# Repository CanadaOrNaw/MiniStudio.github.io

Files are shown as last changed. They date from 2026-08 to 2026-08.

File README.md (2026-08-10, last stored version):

# Mini Studio 16 website

This repository publishes the static Mini Studio 16 project site.

The firmware, CAD sources, tests, documentation, and development history live in [CanadaOrNaw/Mini-Studio-16](https://github.com/CanadaOrNaw/Mini-Studio-16). The files here are a dependency-free build artifact generated from that repository.

## GitHub Pages setting

In **Settings → Pages**, choose **Deploy from a branch**, select **main** and **/(root)**, then save.

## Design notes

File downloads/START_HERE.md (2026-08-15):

# Start here: Mini Studio 16

This page is for someone who has never flashed an ESP32 before. You do not
need to install a DAW or compile source code.

Mini Studio 16 is still a pre-hardware alpha. The downloadable firmware passes
desktop tests and compiles for the Cardputer-ADV, but the first physical-device
test has not happened yet. Keep the original M5Stack factory firmware available
so you can restore it if needed.

## You need

- one **M5Stack Cardputer-ADV** (not the older Cardputer);
- one USB-C **data** cable—some charging-only cables do not carry data;
- one FAT32 microSD card, 32 GB or smaller for the least-friction first test;
- a Windows, macOS or Linux computer;
- the optional printed cradle only if you want it.

The Audio Cap is optional. Do not buy or assemble it for the first Cardputer
test. Its exact shopping list and two-part enclosure are covered later in
[`AUDIO_CAP_BUILD_GUIDE.md`](AUDIO_CAP_BUILD_GUIDE.md).

## The three steps

### 1. Download the verified package

The easy way — no account needed:

1. Open the [Releases page](https://github.com/CanadaOrNaw/Mini-Studio-16/releases/latest).
2. Under **Assets**, download the one file whose name ends in
   `-package.zip`. Ignore the automatic "Source code" downloads — those are
   the program's source, not the ready-to-flash package.
3. Unzip it into a new empty folder.

The developer way — only if you want the newest unreleased build:

1. Open [Build v3 alpha](https://github.com/CanadaOrNaw/Mini-Studio-16/actions/workflows/build-v3-alpha.yml).
2. Open the newest green run for the `main` branch.
3. At the bottom, download the artifact named
   `microgroove-v3-alpha-cardputer-adv`. **This path always requires a free
   GitHub account sign-in, and each run's artifact is deleted about 90 days
   after the run** — if the download link is gone or gives a 404, use the
   Releases page above instead.
4. Unzip it into a new empty folder.

The file for a first Cardputer flash is:

`mini-studio-16-dual-role.bin`

It contains both USB modes and boots into Normal mode first. Do not flash the
smaller application-only `firmware.bin` at address zero.

### 2. Flash it

Follow [`FLASHING.md`](FLASHING.md). That guide includes Windows, macOS and
Linux commands, how to find the port, the Cardputer G0 download-mode sequence,
the exact `0x0` address, recovery steps and separate optional Audio Cap flashing.

### 3. Prepare the SD card

1. Format the card as **FAT32** with an MBR partition table ("MBR" is the
   older, more compatible partition style — most cards 32 GB or smaller ship
   that way already). Windows: right-click the card in Explorer → Format →
   FAT32 (Windows cannot FAT32-format cards larger than 32 GB — use a 32 GB
   or smaller card). macOS: Disk Utility → Erase → format "MS-DOS (FAT)",
   scheme "Master Boot Record". Linux: `mkfs.vfat -F 32` on the card's
   partition.
2. Open `Mini-Studio-16_SD.zip` from the downloaded package.
3. Copy its `groovebox` folder to the root of the SD card.
4. Safely eject the card and insert it into the powered-off Cardputer.
5. Switch the Cardputer on.

The first screen lets you keep Normal USB mode or switch to USB Host mode. Use
Normal mode for the first test. Press any key other than `Tab` to continue.

## Make the first sound

1. Keep headphone volume low or use the built-in speaker.
2. Hold the `=` key (LOAD) until the load completes — a hold takes about half
   a second.
3. Tap the `n` key (SONG) so the whole factory song plays, not just one
   pattern.
4. Press the space bar (PLAY).
4. Use the [interactive button map](https://canadaornaw.github.io/MiniStudio.github.io/#controls)
   or the included `mini-studio-16-button-layout.svg` while learning the pages.

The factory project uses built-in drum engines, so it should make sound even if
sample files were copied incorrectly.

After that basic regression, tap `ctrl` to CHORD and press
`fn shift a s d f g` to play I–VII. Continue to KO for momentary punch
effects and MEDO for the five performance roles. The complete context map and
manual are included in the package.

## If it does not work

- Nothing appears as a serial port: try another known data cable and USB port.
- Flashing cannot connect: repeat the exact G0 sequence in `FLASHING.md`.
- It boots but the SD card is missing: reformat as FAT32/MBR and copy the
  `groovebox` folder—not the outer ZIP—to the card root.
- It makes no sound: lower then raise the Mini Studio volume, unplug headphones,
  and rerun the factory-project steps.
- It resets, becomes hot, smells unusual or the display flickers: power it off
  and record the symptom before trying again.

Once the basic boot/audio pass works, use
[`CARDPUTER_TESTING.md`](https://github.com/CanadaOrNaw/Mini-Studio-16/blob/main/docs/CARDPUTER_TESTING.md) and record measured results. That
physical evidence is the remaining engineering gate.

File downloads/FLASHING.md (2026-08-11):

# Flash Mini Studio 16 without compiling it

This guide writes one already-built image to a Cardputer-ADV. It does not
require PlatformIO, Arduino IDE or a DAW.

## Before you start

You need the unzipped download described in [`START_HERE.md`](START_HERE.md)
(the Releases package, or the sign-in-gated Actions artifact for unreleased
builds), a USB-C **data** cable and Python 3.

Install the pinned flashing tool:

| Computer | Command |
| --- | --- |
| Windows PowerShell | `py -m pip install esptool==4.8.1` |
| macOS Terminal | `python3 -m pip install esptool==4.8.1` |
| Linux terminal | `python3 -m pip install --user esptool==4.8.1` |

In the commands below, Windows users type `py` where the guide says `python3`.

## 1. Find the Cardputer port

1. Set the Cardputer side power switch to **OFF**.
2. Hold the side `G0` button.
3. While holding `G0`, connect the USB-C data cable to the computer.
4. Release `G0`. The screen may stay blank; that is normal download mode.

M5Stack documents this same sequence in its
[Cardputer-ADV download-mode guide](https://docs.m5stack.com/en/core/Cardputer-Adv).

Find the new port:

- Windows: open **Device Manager → Ports (COM & LPT)** and note a name such as
  `COM5`.
- macOS: run `ls /dev/cu.usb*` and note the new path.
- Linux: run `ls /dev/ttyACM* /dev/ttyUSB* 2>/dev/null` and note the new path.

Use that exact value in place of `PORT` below.

## 2. Flash the combined Cardputer image

Open a terminal in the unzipped artifact folder. First erase the old flash:

```bash
python3 -m esptool --chip esp32s3 --port PORT erase_flash
```

Then write the combined image at address `0x0`:

```bash
python3 -m esptool --chip esp32s3 --port PORT --baud 460800 write_flash 0x0 mini-studio-16-dual-role.bin
```

Wait for `Hash of data verified`. Disconnect USB, move the side switch to ON,
then reconnect USB only if you want charging/serial. The first boot selects
Normal USB mode. `Tab` switches between Normal and USB Host after a validated
reboot; it does not require another flash.

Erasing replaces the factory firmware and settings stored in flash. It does not
erase the removable microSD card.

## 3. Verify the downloaded files (recommended)

The artifact includes `SHA256SUMS.txt`. On macOS or Linux:

```bash
sha256sum -c SHA256SUMS.txt
```

macOS may provide `shasum -a 256` instead of `sha256sum`; compare the result for
`mini-studio-16-dual-role.bin` with its line in `SHA256SUMS.txt`. On Windows:

```powershell
certutil -hashfile mini-studio-16-dual-role.bin SHA256
```

Compare the printed value with the same filename in `SHA256SUMS.txt`. Do not
flash a file whose hash differs.

## Optional: flash the ATOM Lite Audio Cap controller

Do this **before** assembling the cap. The ATOM must be by itself—not connected
to the Cardputer, PCM1808 or power harness.

1. Connect the ATOM Lite to the computer with its USB-C data cable. M5Stack says
   the original ATOM Lite enters download mode when connected for flashing.
2. Find its port using the same operating-system steps above.
3. In the artifact folder run:

```bash
python3 -m esptool --chip esp32 --port PORT erase_flash
python3 -m esptool --chip esp32 --port PORT --baud 460800 write_flash 0x0 mini-studio-audio-cap-atom-lite/mini-studio-audio-cap-atom-lite.bin
```

4. Wait for hash verification and unplug the programming cable.
5. Continue with [`AUDIO_CAP_BUILD_GUIDE.md`](AUDIO_CAP_BUILD_GUIDE.md).

The ATOM's USB cable is only used while programming. It is not present in the
finished one-plug Cardputer-powered cap.

## Recovery and common errors

| Message or symptom | What to do |
| --- | --- |
| `Failed to connect` | Repeat OFF → hold G0 → connect USB → release G0; then retry. |
| Port disappears | Try a different data cable/USB port and avoid an unpowered hub. |
| `Permission denied` on Linux | Add your user to the serial-port group (often `dialout`), sign out/in, then retry. Do not run random commands as root. |
| Write fails at high baud | Repeat the write command with `--baud 115200`. |
| Cardputer boot-loops after a completed write | Re-enter G0 mode, erase, verify the image hash, and write again at `0x0`. |
| Need the factory firmware | Follow M5Stack's [Cardputer-ADV restore guide](https://docs.m5stack.com/en/guide/restore_factory/cardputer_adv). |

Developers who intentionally want to compile or upload from source can use the
PlatformIO commands in the main README. Beginners should use the merged images
above because they contain the bootloader, partition table and application at
the correct addresses.

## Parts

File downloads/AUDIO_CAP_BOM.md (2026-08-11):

# Audio Cap exact shopping list

This page is generated from `hardware/audio-cap/bom.json`. Every link
opens one exact product SKU—not a search or category page. Price and stock
can change. If a link is unavailable, search the printed manufacturer part
number or ASIN and do not substitute a visually similar part.

Marketplace listings (Amazon ASINs) rot without notice and cannot be
checked by automation; they were last hand-verified on 2026-08-11.
Before paying, confirm the page still shows the exact part named in
its row — for the PCM1808 module that means the master-mode variant
with its own onboard oscillator (a small metal can on the board),
an installed I2S header, and a 3.5 mm jack.

Buy one row of each item unless the quantity column says otherwise. An adult
should place orders and supervise cutting/stripping the four power leads.

## Canada

| Qty | Exact part | Seller SKU | Buy |
| ---: | --- | --- | --- |
| 1 | **M5Stack C008** — ATOM Lite ESP32 controller with factory-installed USB-C and Grove connectors | `2221-C008-ND` | [DigiKey Canada](https://www.digikey.ca/en/products/detail/m5stack-technology-co-ltd/C008/12088545) |
| 1 | **Rakstore ASIN B09CDCLXQC** — Preassembled PCM1808 stereo line-input I2S module with 3.5 mm jack, installed I2S header and USB-C 5 V input | `ASIN B09CDCLXQC` | [Amazon Canada](https://www.amazon.ca/Rakstore-PCM1808-Stereo-Single-Ended-Digital/dp/B09CDCLXQC) |
| 1 | **Samtec TSW-107-08-G-D** — 2x7, 2.54 mm through-hole male terminal strip; 5.84 mm mating posts and 5.08 mm wire-side tails | `612-TSW-107-08-G-D-ND` | [DigiKey Canada](https://www.digikey.ca/en/products/detail/samtec-inc/TSW-107-08-G-D/1101667) |
| 1 | **Adafruit 4635** — Pack of 40 factory-crimped 200 mm male-to-female silicone jumper leads, 24 AWG | `1528-4635-ND` | [DigiKey Canada](https://www.digikey.ca/en/products/detail/adafruit-industries-llc/4635/13157993) |
| 1 | **M5Stack A096** — Grove-to-Dupont conversion cable set, 20 cm, five male and five female sets | `2221-A096-ND` | [DigiKey Canada](https://www.digikey.ca/en/products/detail/m5stack-technology-co-ltd/A096/16679751) |
| 2 | **WAGO 221-413** — Three-port compact lever splice; one for +5 V and one for GND, hidden inside the cap | `2946-221-413-ND` | [DigiKey Canada](https://www.digikey.ca/en/products/detail/wago-corporation/221-413/13549610) |
| 1 | **MECCANIXITY ASIN B0DWK3NXG6** — Short USB-C male to red/black bare-wire 5 V pigtail, 22 AWG; hidden inside the cap | `ASIN B0DWK3NXG6` | [Amazon Canada](https://www.amazon.ca/MECCANIXITY-Pigtail-Connector-Equipment-Installed/dp/B0DWK3NXG6) |
| 2 | **Essentra Components 50M020040P006** — M2 x 0.4 x 6 mm nylon pan-head Phillips machine screw | `145-50M020040P006-ND` | [DigiKey Canada](https://www.digikey.ca/en/products/detail/essentra-components/50M020040P006/11639321) |
| 2 | **Essentra Components 04M020040HN** — M2 x 0.4 nylon hex nut | `RPC7084-ND` | [DigiKey Canada](https://www.digikey.ca/en/products/detail/essentra-components/04M020040HN/9677098) |

## United States

| Qty | Exact part | Seller SKU | Buy |
| ---: | --- | --- | --- |
| 1 | **M5Stack C008** — ATOM Lite ESP32 controller with factory-installed USB-C and Grove connectors | `2221-C008-ND` | [DigiKey](https://www.digikey.com/en/products/detail/m5stack-technology-co-ltd/C008/12088545) |
| 1 | **Rakstore ASIN B09CDCLXQC** — Preassembled PCM1808 stereo line-input I2S module with 3.5 mm jack, installed I2S header and USB-C 5 V input | `ASIN B09CDCLXQC` | [Amazon US](https://www.amazon.com/Rakstore-PCM1808-Stereo-Single-Ended-Digital/dp/B09CDCLXQC) |
| 1 | **Samtec TSW-107-08-G-D** — 2x7, 2.54 mm through-hole male terminal strip; 5.84 mm mating posts and 5.08 mm wire-side tails | `612-TSW-107-08-G-D-ND` | [DigiKey](https://www.digikey.com/en/products/detail/samtec-inc/TSW-107-08-G-D/1101667) |
| 1 | **Adafruit 4635** — Pack of 40 factory-crimped 200 mm male-to-female silicone jumper leads, 24 AWG | `1528-4635-ND` | [DigiKey](https://www.digikey.com/en/products/detail/adafruit-industries-llc/4635/13157993) |
| 1 | **M5Stack A096** — Grove-to-Dupont conversion cable set, 20 cm, five male and five female sets | `2221-A096-ND` | [DigiKey](https://www.digikey.com/en/products/detail/m5stack-technology-co-ltd/A096/16679751) |
| 2 | **WAGO 221-413** — Three-port compact lever splice; one for +5 V and one for GND, hidden inside the cap | `2946-221-413-ND` | [DigiKey](https://www.digikey.com/en/products/detail/wago-corporation/221-413/13549610) |
| 1 | **EAHOSUCC ASIN B0DCGJY4MR** — Short USB-C male to red/black bare-wire 5 V pigtail, 22 AWG; hidden inside the cap | `ASIN B0DCGJY4MR` | [Amazon US](https://www.amazon.com/EAHOSUCC-22AWG-Pigtail-Equipment-Installed/dp/B0DCGJY4MR) |
| 2 | **Essentra Components 50M020040P006** — M2 x 0.4 x 6 mm nylon pan-head Phillips machine screw | `145-50M020040P006-ND` | [DigiKey](https://www.digikey.com/en/products/detail/essentra-components/50M020040P006/11639321) |
| 2 | **Essentra Components 04M020040HN** — M2 x 0.4 nylon hex nut | `RPC7084-ND` | [DigiKey](https://www.digikey.com/en/products/detail/essentra-components/04M020040HN/9677098) |

## European Union

| Qty | Exact part | Seller SKU | Buy |
| ---: | --- | --- | --- |
| 1 | **M5Stack C008** — ATOM Lite ESP32 controller with factory-installed USB-C and Grove connectors | `2221-C008-ND` | [DigiKey Germany](https://www.digikey.de/en/products/detail/m5stack-technology-co-ltd/C008/12088545) |
| 1 | **Rakstore ASIN B0D1NNR21W** — Preassembled PCM1808 stereo line-input I2S module with 3.5 mm jack, installed I2S header and USB-C 5 V input | `ASIN B0D1NNR21W` | [Amazon Germany](https://www.amazon.de/-/en/RAKSTORE-PCM1808-Stereo-Single-Ended-Digital/dp/B0D1NNR21W) |
| 1 | **Samtec TSW-107-08-G-D** — 2x7, 2.54 mm through-hole male terminal strip; 5.84 mm mating posts and 5.08 mm wire-side tails | `612-TSW-107-08-G-D-ND` | [DigiKey Germany](https://www.digikey.de/en/products/detail/samtec-inc/TSW-107-08-G-D/1101667) |
| 1 | **Adafruit 4635** — Pack of 40 factory-crimped 200 mm male-to-female silicone jumper leads, 24 AWG | `1528-4635-ND` | [DigiKey Germany](https://www.digikey.de/en/products/detail/adafruit-industries-llc/4635/13157993) |
| 1 | **M5Stack A096** — Grove-to-Dupont conversion cable set, 20 cm, five male and five female sets | `2221-A096-ND` | [DigiKey Germany](https://www.digikey.de/en/products/detail/m5stack-technology-co-ltd/A096/16679751) |
| 2 | **WAGO 221-413** — Three-port compact lever splice; one for +5 V and one for GND, hidden inside the cap | `2946-221-413-ND` | [DigiKey Germany](https://www.digikey.de/en/products/detail/wago-corporation/221-413/13549610) |
| 1 | **Greluma ASIN B0DNF37FPX** — Short USB-C male to red/black bare-wire 5 V pigtail, 22 AWG; hidden inside the cap | `ASIN B0DNF37FPX` | [Amazon Germany](https://www.amazon.de/-/en/Greluma-22AWG-Pigtail-Cable-Power/dp/B0DNF37FPX) |
| 2 | **Essentra Components 50M020040P006** — M2 x 0.4 x 6 mm nylon pan-head Phillips machine screw | `145-50M020040P006-ND` | [DigiKey Germany](https://www.digikey.de/en/products/detail/essentra-components/50M020040P006/11639321) |
| 2 | **Essentra Components 04M020040HN** — M2 x 0.4 nylon hex nut | `RPC7084-ND` | [DigiKey Germany](https://www.digikey.de/en/products/detail/essentra-components/04M020040HN/9677098) |

## Do not substitute these details

- The harness is Adafruit 4635, **24 AWG**. Ordinary 28-AWG jumper leads
  are not allowed in the WAGO power branches.
- The PCM1808 listing must show an installed I2S header, 3.5 mm input and
  USB-C 5 V input, and the board must be no larger than 50.5 × 30.5 mm.
- The cap header is Samtec `TSW-107-08-G-D`; print and use the fit gauge
  before printing the complete enclosure.
- The USB-C pigtail stays hidden inside the closed cap. It is not a second
  external power cable.

Continue with [`AUDIO_CAP_BUILD_GUIDE.md`](AUDIO_CAP_BUILD_GUIDE.md).

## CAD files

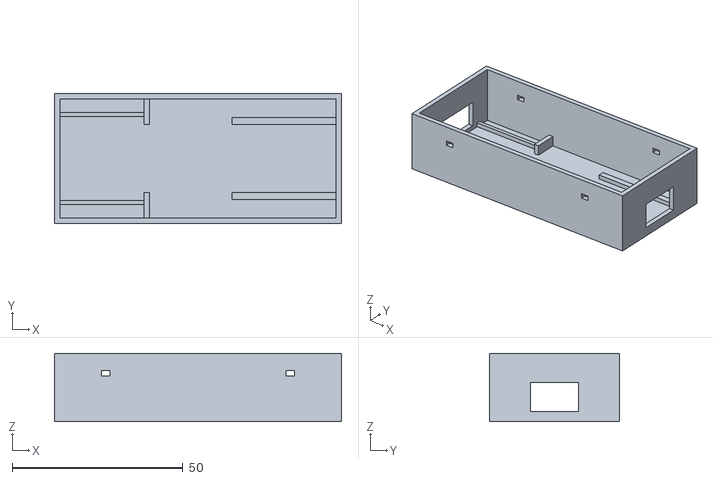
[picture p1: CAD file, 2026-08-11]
downloads/audio-cap-base.stl
84.0 x 38.0 x 20.0

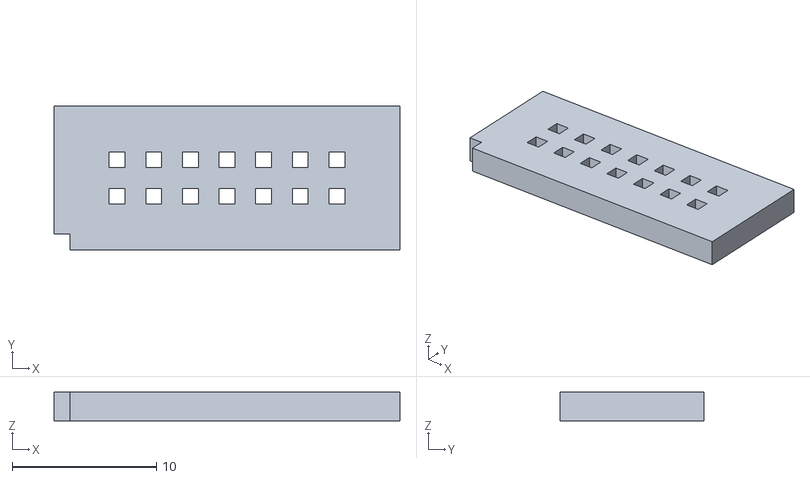
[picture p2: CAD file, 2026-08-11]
downloads/audio-cap-14pin-fit-gauge.stl
24.0 x 10.0 x 2.00

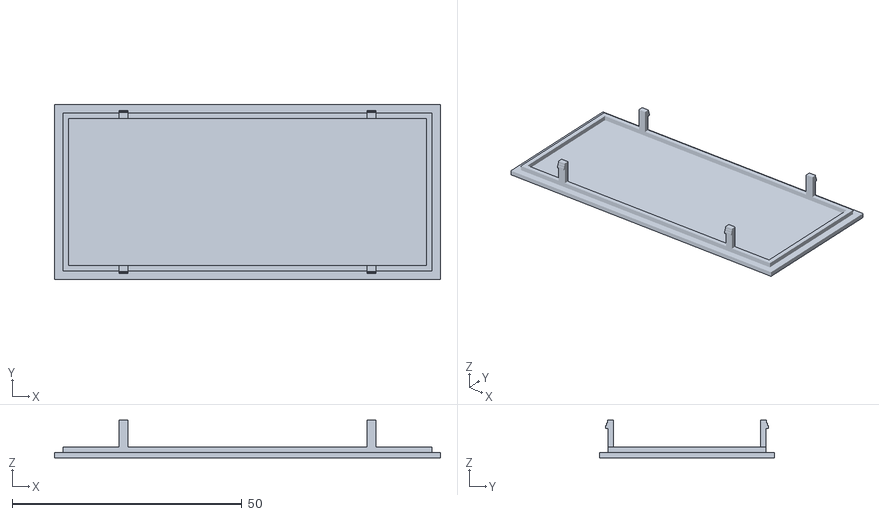
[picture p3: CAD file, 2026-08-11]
downloads/audio-cap-lid.stl
84.0 x 38.0 x 8.20

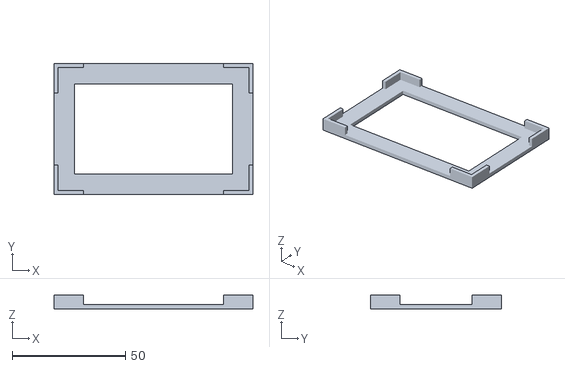
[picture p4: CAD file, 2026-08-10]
downloads/mini-studio-16-bench-cradle.stl
88.0 x 58.0 x 6.00

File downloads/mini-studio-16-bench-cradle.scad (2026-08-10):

// Mini Studio 16 open bench cradle for M5Stack Cardputer-ADV.
// Original parametric design; pre-hardware fit prototype.
// Published device envelope: 84 x 54 mm. Default clearance: 0.30 mm/side.

device_x = 84.0;
device_y = 54.0;
clearance = 0.30;
outer_x = 88.0;
outer_y = 58.0;
base_height = 2.0;
wall_height = 6.0;
center_opening_x = 70.0;
center_opening_y = 40.0;
side_clip_span_y = 32.0;
end_clip_span_x = 62.0;

cavity_x = device_x + 2 * clearance;
cavity_y = device_y + 2 * clearance;
wall_x = (outer_x - cavity_x) / 2;
wall_y = (outer_y - cavity_y) / 2;

module centered_cube(size) {
    translate([-size[0] / 2, -size[1] / 2, 0]) cube(size);
}

union() {
    // Ventilated bottom frame.
    difference() {
        centered_cube([outer_x, outer_y, base_height]);
        translate([0, 0, -0.1])
            centered_cube([center_opening_x, center_opening_y, base_height + 0.2]);
    }

    // Four open corner guides. Side/end centers stay clear for ports.
    for (sx = [-1, 1])
        for (sy = [-1, 1]) {
            translate([sx * (cavity_x / 2 + wall_x / 2),
                       sy * (cavity_y / 2 - side_clip_span_y / 4), 0])
                centered_cube([wall_x, side_clip_span_y / 2, wall_height]);
            translate([sx * (cavity_x / 2 - end_clip_span_x / 4),
                       sy * (cavity_y / 2 + wall_y / 2), 0])
                centered_cube([end_clip_span_x / 2, wall_y, wall_height]);
        }
}

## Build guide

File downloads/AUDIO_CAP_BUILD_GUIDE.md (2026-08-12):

# Build the Mini Studio 16 Audio Cap

This is the beginner version. An adult should supervise a child during printing,
wire stripping/crimping, first power and headphone use. Nothing is soldered and
no circuit board is ordered or fabricated.

## What you are making

When closed, the cap has a 3.5 mm line-input hole, one 14-pin plug, and four
small snap windows on its long sides. It plugs directly into the Cardputer.
There is no second power cord: the Cardputer powers it through the 14-pin
plug. The ATOM's physical button and status light are inside the closed lid
in this revision, so pairing and status use the Cardputer commands
(`cap-pair`, `cap-status`) shown in step 8; a button plunger and light window
are planned for enclosure rev-B.

## 1. Buy the parts

Open the human-readable
[`AUDIO_CAP_BOM.md`](AUDIO_CAP_BOM.md) and use the table for your region. It is
generated from the canonical [`hardware/audio-cap/bom.json`](https://github.com/CanadaOrNaw/Mini-Studio-16/blob/main/hardware/audio-cap/bom.json)
and tested to contain exact purchase SKUs for Canada, the United States and the
European Union.

| Qty | Part | The picture must show |
| ---: | --- | --- |
| 1 | M5Stack ATOM Lite C008 | white 24 mm square case, USB-C, Grove socket |
| 1 | Rakstore PCM1808 stereo I2S module (exact regional ASIN in BOM) | 3.5 mm jack; installed DOUT/BCK/LRCK/GND pins; USB-C 5 V input |
| 1 | Samtec `TSW-107-08-G-D` header | two rows of seven at 2.54 mm; exact 5.84/5.08 mm posts |
| 1 pack | Adafruit `4635` precrimped leads | 40 male-to-female leads; silicone insulation; **24 AWG** |
| 1 | M5Stack A096 Grove-to-Dupont lead set | factory-made Grove plug and separate Dupont ends |
| 2 | WAGO 221-413 three-port lever splices | genuine clear body/orange levers, three holes each |
| 1 | exact regional 22-AWG USB-C power pigtail from the BOM | male USB-C; red/black bare-wire ends |
| 2 | Essentra `50M020040P006` M2 x 6 nylon screws | module retainers; not lid fasteners |
| 2 | Essentra `04M020040HN` M2 nylon nuts | match the retainer screws |

Do not buy a bare PCM1808 chip, a board with empty header holes, or a module
larger than 50.5 x 30.5 mm. Do not substitute ordinary thin 28-AWG jumpers in
the power splices. Every BOM route names one exact SKU; if a link is out of
stock, search the printed manufacturer part number or ASIN rather than choosing
a look-alike.

## 2. Print the fit gauge first

Download and print:

1. `audio-cap-14pin-fit-gauge.stl`;
2. `audio-cap-base.stl` only after the header fits the gauge;
3. `audio-cap-lid.stl` after the purchased modules sit in the base.

Recommended first pass: PLA, 0.20 mm layers, 0.40 mm nozzle, 3 walls, 20% infill,
no support. The base and lid print flat exactly as downloaded — the lid prints
plate-down with its lip and four snap fingers pointing up, and is flipped over
for assembly. The gauge's one notched corner marks header pin 1 (the `G3`
end); keep that notch in the same corner as pin 1 whenever you test-fit.
Press the exact Samtec header into the small fit gauge by itself—never use the
Cardputer as a hammer. If it needs force, scale only X/Y by 101%, reprint the
gauge and record the result.

The generated models are watertight and have checked bounds. Their real fit is
unverified until the Cardputer and the exact retail module revision arrive.

## 3. Flash before assembly

The step-by-step first-time instructions are in [`FLASHING.md`](FLASHING.md).
Keep the cap parts away from the Cardputer. Connect only the ATOM Lite to your
computer with a normal USB-C data cable. The easiest route flashes the merged
`mini-studio-audio-cap-atom-lite.bin` from the verified Actions artifact at
offset `0x0`. Developers can instead run:

```bash
pio run -e mini-studio-audio-cap-atom-lite -t upload --upload-port PORT
```

Replace `PORT` with the port shown by PlatformIO. The RGB should light and the
serial monitor should print `MS16_AUDIO_CAP_READY`. Unplug the USB-C cable. It
is a programming cable used before assembly; it is not part of the finished cap.

## 4. Make the signal harness

Power must be off. Use the table exactly. Slide the female ends of five
Adafruit 4635 leads onto the rear pins of the 2x7 header, then slide the other
ends onto the named ATOM sockets. Double-check each lead against the table
before moving on — this revision has no keyed holder (planned for rev-B), so
the table and the gauge's pin-1 notch are your orientation references.

| Header position | Connect to |
| --- | --- |
| pin 1 G3 | ATOM G19 |
| pin 3 G4 | ATOM G21 |
| pin 5 G6 | ATOM G22 |
| pin 12 G13 | ATOM G23 |
| pin 13 G5 | ATOM G33 |

Leave header pins 2, 7, 8, 9, 10, 11 and 14 completely empty. Pin 2 is `5VIN`,
not cap power. A wrong power pin can damage the devices.

Connect the ADC using factory-crimped leads:

| PCM1808 | ATOM |
| --- | --- |
| DOUT | G25 |
| BCK | G26 (yellow Grove wire) |
| LRCK | G32 (white Grove wire) |
| GND | ground branch below |
| MCLK | leave empty |

## 5. Make the hidden power branch

This step uses **only the 24-AWG Adafruit 4635 leads and the 22-AWG USB-C
pigtail**. Common 28-AWG signal jumpers are not an allowed substitute. An adult
cuts the unused connector off four Adafruit leads—one for header 5 V, one for
header ground, one for ATOM 5 V and one for ATOM ground—and strips 9–11 mm at
the cut end.

Lift every orange lever. Put only straight bare copper under a lever, then close
it and tug gently. No copper should remain visible.

- `+5 V` splice: header pin 6 `5VOUT`, ATOM `5V`, red ADC-power wire.
- `GND` splice: header pin 4 `GND`, ATOM `GND`, black ADC-power wire.

Plug the short ADC-power connector into the PCM1808 module and tuck the entire
branch into its printed channel. Both lever splices and the ADC plug stay inside
the cap. No wire exits the enclosure.

The USB-C pigtail red/black ends are already bare; trim or restrip them to the
same 9–11 mm length if necessary. Never twist 5 V and GND together.

## 6. Check before power

Do these five checks aloud:

- “There is exactly one outside plug: the 14-pin header.”
- “Header pin 2 is empty.”
- “Header pin 6 goes to the +5 V splice.”
- “Header pin 4 goes to the ground splice.”
- “No loose copper can touch another pin.”

Use a multimeter continuity check before first power. `5VOUT` to GND must not
be a short. For the first prototype, place a multimeter in series with the
5VOUT branch and record idle, pairing and connected current. This temporary
bench measurement is removed before closing the finished cap.

## 7. Close and plug in

**Known rev-B gap — read before closing.** With straight precrimped jumpers in
the ATOM's bottom sockets, the ATOM-plus-housing stack is taller than this
revision's interior, so the current base closes over the PCM1808 and harness
but not over a fully jumpered ATOM. Until enclosure rev-B (deeper interior,
retainer bosses, wire channels), bench-test the cap open, or close the lid
with the ATOM resting beside its bay unlidded. Record the measured stack
height of your real parts in `CARDPUTER_TESTING.md` so rev-B uses evidence,
not estimates. The nylon M2 retainers from the BOM are for rev-B.

Seat the PCM1808 jack in its end window. Set the lid on the base — its
locating lip squares it automatically — then press down over each corner until
all four snap fingers click into the side windows. To reopen, press the two
visible nubs on one long side inward through their windows with a plastic
pick and lift; do not pry at the Cardputer.

With the Cardputer off, align the 14-pin plug (the bare header itself is not
keyed — match pin 1 `G3` to the gauge's notched corner and the EXT port's pin-1
end) and push straight in. Never offset it by one pin. Power the Cardputer from its battery or normal USB-C.

## 8. Use it

The line input accepts a stereo 3.5 mm source; start the source volume low.
Mini Studio sums it to mono. Line monitoring defaults off:

```bash
python tools/ministudio_cli.py --port PORT cap-status
python tools/ministudio_cli.py --port PORT cap-monitor 25
python tools/ministudio_cli.py --port PORT cap-pair
```

**First-power acceptance check (do this before anything else):** run
`cap-status` and look for `adc=1`. That single flag is the proof your
PCM1808 module is the required self-clocked master variant. If it stays
`adc=0`, or `cap-monitor` plays audio noticeably at the wrong pitch, the
purchased module is a slave-only or wrong-oscillator variant (PCM1808 needs
an external system clock the ATOM cannot supply — the module must carry its
own oscillator). Stop and exchange the module; no wiring change can fix it.
Record the result in `CARDPUTER_TESTING.md`.

Put one Bluetooth speaker/headset in pairing mode, then run `cap-pair` (the
ATOM's physical button also works whenever the lid is open). The first
discovered audio-rendering device is selected.

| RGB | Meaning |
| --- | --- |
| blue | ADC/bridge ready |
| purple | discovering/pair armed |
| green | Bluetooth audio connected |
| red | firmware/I2S/SPI fault |

## 9. First-hardware checklist

Do not call the cap finished until all results are recorded in
`docs/CARDPUTER_TESTING.md`: connector fit, 5VOUT current and sag, heat, silence
noise, line clipping level, left/right polarity, ten-minute CRC/sequence soak,
30-minute Bluetooth output, simultaneous SD recording, battery runtime, pair/
reconnect with three different sinks, and five power cycles.

If anything becomes hot, smells unusual, flickers when audio peaks, or reports
CRC/sequence errors, turn the Cardputer off and reopen the cap. Do not “fix” a
power problem by adding a second power cable; record the failure and revise the
module choice or power budget while preserving the one-plug design.

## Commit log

2026-08-10 Publish Mini Studio 16 website
    [mini-studio-16-bench-cradle.scad, mini-studio-16-bench-cradle.stl]
2026-08-10 Publish Audio Cap build package and beginner guides
    [mini-studio-audio-cap-base.stl, mini-studio-audio-cap-bom.csv, mini-studio-audio-cap-lid.stl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]
2026-08-10 Remove custom-PCB Audio Cap package
    [mini-studio-audio-cap-base.stl, mini-studio-audio-cap-bom.csv, mini-studio-audio-cap-lid.stl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]
2026-08-11 Publish solderless one-plug Audio Cap package
    [audio-cap-14pin-fit-gauge.stl, audio-cap-base.stl, audio-cap-lid.stl]
2026-08-11 Publish exact BOM and beginner flashing guides
2026-08-11 Publish site from Mini-Studio-16@f978bd991cc5
    [audio-cap-14pin-fit-gauge.stl, audio-cap-base.stl, audio-cap-lid.stl]
